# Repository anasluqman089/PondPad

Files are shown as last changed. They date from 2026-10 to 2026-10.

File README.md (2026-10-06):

# PondPad



Hello Everyone! PondPad is a custom arcade-style macropad built using a Seeed XIAO ESP32-C3. It uses 5 button, a TFT display and Bluetooth for quick shortcut, media, and text actions.

## Project contents

- Firmware: [Firmware/PondPadArcade.ino](Firmware/PondPadArcade.ino)
- Schematic and PCB: [PCB & Schematic/PondPad.kicad_sch](PCB%20%26%20Schematic/PondPad.kicad_sch) and [PCB & Schematic/PondPad.kicad_pcb](PCB%20%26%20Schematic/PondPad.kicad_pcb)
- Gerber output: [Production/Gerber](Production/Gerber)
- CAD files: [CAD](CAD)
- BOM: [BOM.csv](BOM.csv)

## Hardware

The current PCB is designed around:

- 1x Seeed XIAO ESP32-C3-SMD
- 5x Cherry MX-compatible 1.00u PCB switches
- 1x 240x320 ST7789-compatible TFT display
- 1x JST-PH 8-pin display interconnect
- 1x JST-PH 2-pin battery connector
- 4x M2 mounting holes

## BOM

| Name | Qty | Price | Buy Link |
| --- | ---: | --- | --- |
| Cherry MX switch | 5 | $8.75 | https://www.aliexpress.com/item/1005002162885278.html |
| XIAO ESP32-C3 | 1 | $12.00 | https://www.aliexpress.com/item/1005007469761633.html |
| JST PH 1x8 PCB mount | 1 | ~$0.20 | (Most only sells in pack more than 1) |
| JST PH 1x2 PCB mount | 1 | ~$0.20 | (Most only sells in pack more than 1) |
| M2 mounting screw | 4 | ~$0.50 | (Most only sells in pack more than 4) |
| 240x320 TFT display | 1 | $13.00 | https://www.aliexpress.com/item/1005008772378337.html] |
| PCB (With Stencil) | 1 | $7.80 | https://www.aliexpress.com/item/1005012672070003.html] |
| 3D Printing | 1 | ~$10.00 | - |

## Firmware

The firmware is written in Arduino C++.

### Required libraries

Install the following in the Arduino IDE or PlatformIO:

- Adafruit_GFX
- Adafruit_ST7789
- BleKeyboard
- Preferences support is built into the ESP32 core

### Pin map

The firmware expects the following GPIO assignments:

- Display backlight: GPIO 2
- Display reset: GPIO 3
- Display data/command: GPIO 4
- Display chip select: GPIO 5
- Key switches: GPIO 6, 7, 21, 9, 20
- SPI clock: GPIO 8
- SPI MOSI: GPIO 10

## Operation

The device starts in a menu screen and offers:

1. Macro pad mode
2. Fly Catch game
3. Whack-a-Frog game
4. Lily Dodge game
5. High score screen

The macro pad mode sends keyboard shortcuts and media commands over BLE to a paired host.

### Images



### PCB





### CAD





### Schematic

## License

This project is distributed under the repository license. See the [LICENSE](LICENSE) for details.

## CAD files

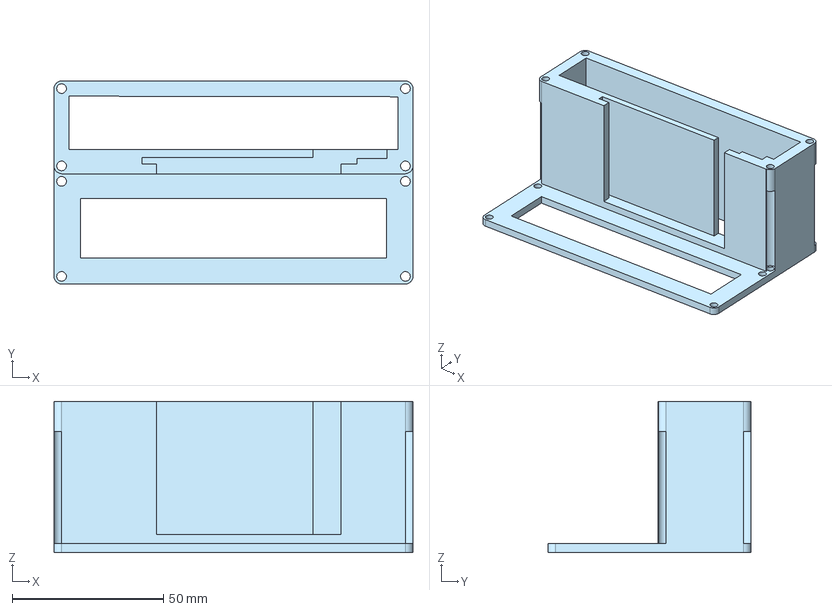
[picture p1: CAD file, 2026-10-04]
CAD/Screen Case & Keyboard Lid.step
118.5 x 67.0 x 50.0 mm

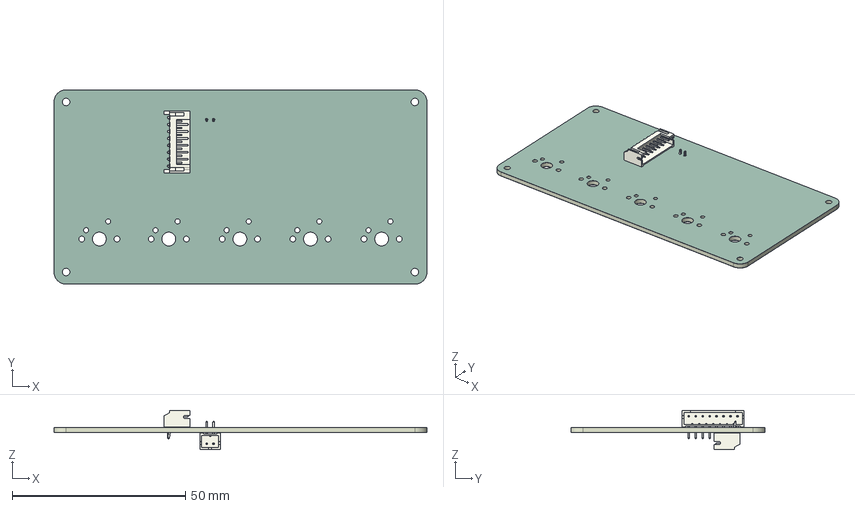
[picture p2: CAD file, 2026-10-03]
PCB & Schematic/PondPad PCB.step
107.5 x 56.0 x 11.4 mm
JST_S8B_PH_K
JST_S2B_PH_K
PonBE4F_soldermask x 2
PonBE4F_PCB

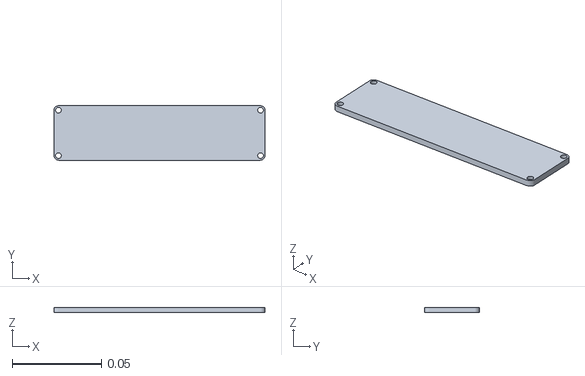
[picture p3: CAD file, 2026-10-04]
Production/3D Printing/Part 3.stl
0.118 x 0.0306 x 0.003

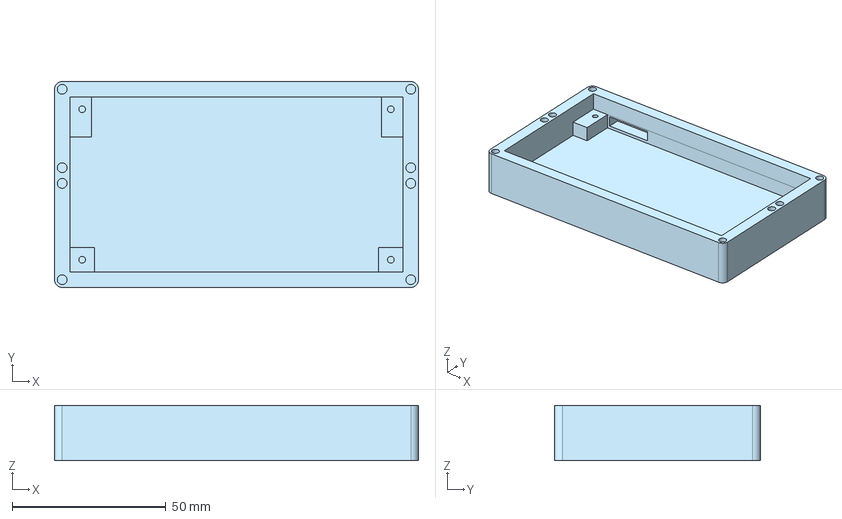
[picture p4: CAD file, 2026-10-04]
CAD/PCB Case.step
118.5 x 67.0 x 18.0 mm

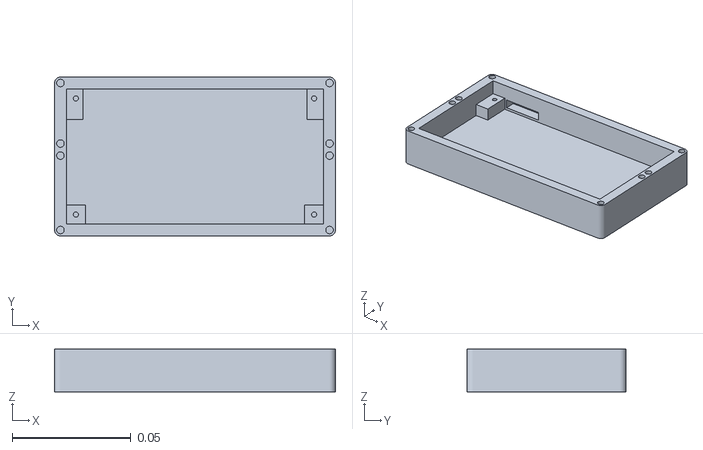
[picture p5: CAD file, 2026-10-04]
Production/3D Printing/Part 1.stl
0.118 x 0.067 x 0.018

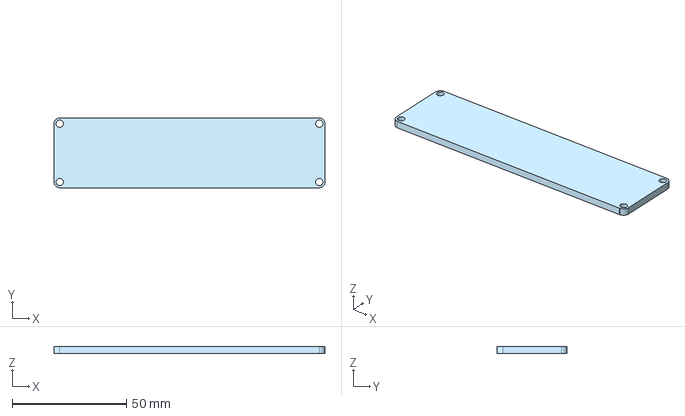
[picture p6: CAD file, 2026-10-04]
CAD/Screen Lid.step
118.5 x 30.6 x 3.00 mm

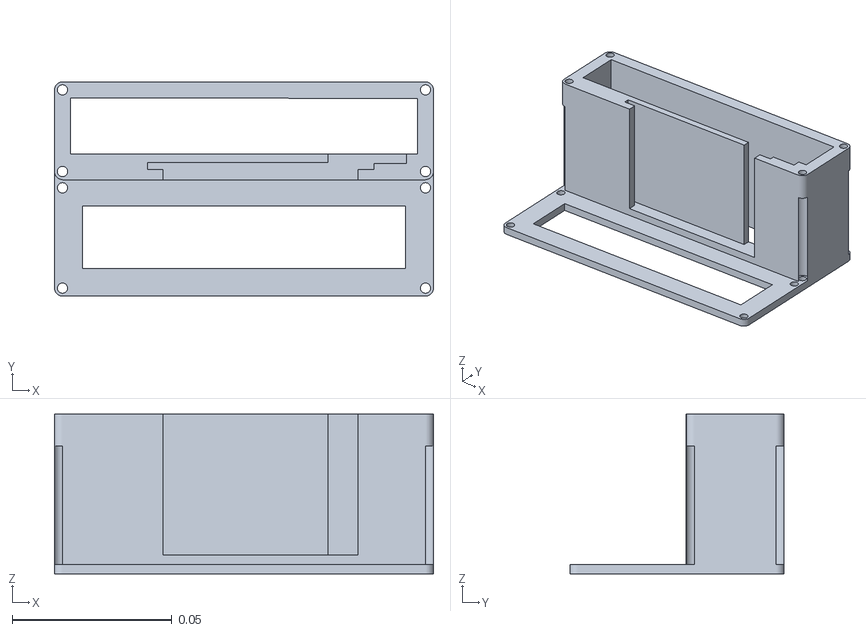
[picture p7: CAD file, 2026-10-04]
Production/3D Printing/Part 2.stl
0.118 x 0.067 x 0.05

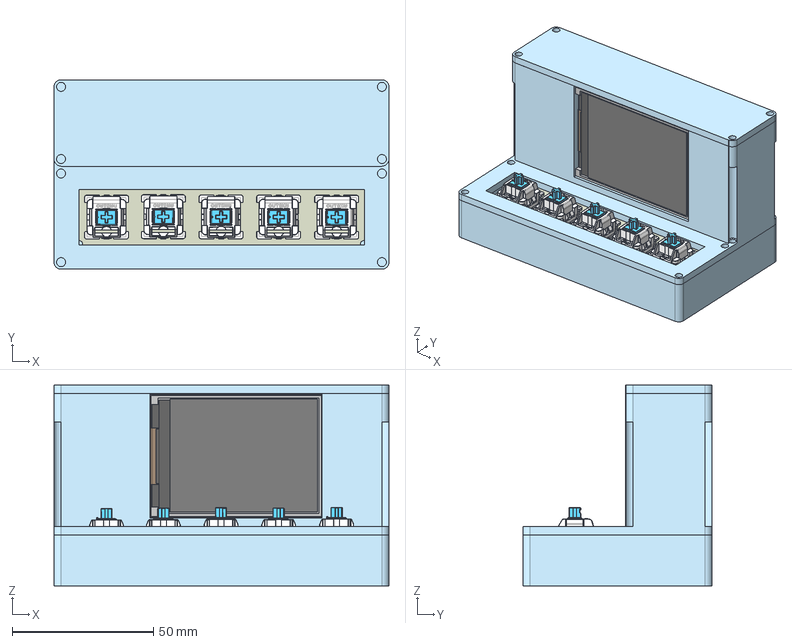
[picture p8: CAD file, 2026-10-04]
CAD/PondPad CAD.step
118.5 x 67.0 x 71.0 mm
Body - Flex
Extrude - Annular rings x 12
Support pins
Extrude - Connector pads x 8
BOSS-EXTRUDE7_9_:1__Körper1
BOSS-EXTRUDE7_7_:1__Körper1
RET__RET x 5
Body - LCD
Pins005
Body - Black tape
PIN__PIN x 10
BOSS-EXTRUDE14_9_:1__Körper1
BOSS-EXTRUDE7_6_:1__Körper1
BOSS-EXTRUDE7_4_:1__Körper1
BOSS-EXTRUDE14_3_:1__Körper1
Pins004
BOSS-EXTRUDE7_8_:1__Körper1
BOSS-EXTRUDE7_5_:1__Körper1
Shield:1__Körper1
U.FL Connector v1:1__Körper1
Cut - PCB
BOSS-EXTRUDE7_3_:1__Körper1
CLICK__CLICK x 5
TOP__TOP x 5
BOTT__BOTT x 5
Button (1):1__Körper1_1
BOSS-EXTRUDE14_10_:1__Körper1
Body - Adhesive
BOSS-EXTRUDE14_5_:1__Körper1
PonBE4F_PCB
Button (1):1__Körper1
BOSS-EXTRUDE14_11_:1__Körper1
Pins007
Main body
BOSS-EXTRUDE14_4_:1__Körper1
Pins006
Support pins001
JST_S8B_PH_K
Pins001
BOSS-EXTRUDE14_2_:1__Körper1
BOSS-EXTRUDE14_6_:1__Körper1
CUT-EXTRUDE5:1__Körper1
BOSS-EXTRUDE7_1_:1__Körper1
BOSS-EXTRUDE14_1_:1__Körper1
U.FL Connector v1:1__Körper3
Pins003
BOSS-EXTRUDE7_2_:1__Körper1
BOSS-EXTRUDE14_12_:1__Körper1
U.FL Connector v1:1__Körper2
BOSS-EXTRUDE14_7_:1__Körper1
Body - Protection
Pins002
BOSS-EXTRUDE14_8_:1__Körper1
MIRROR2:1__Körper1
Pins
Body - Bezel
JST_S2B_PH_K
PCB
CHAMFER9:1__Körper1

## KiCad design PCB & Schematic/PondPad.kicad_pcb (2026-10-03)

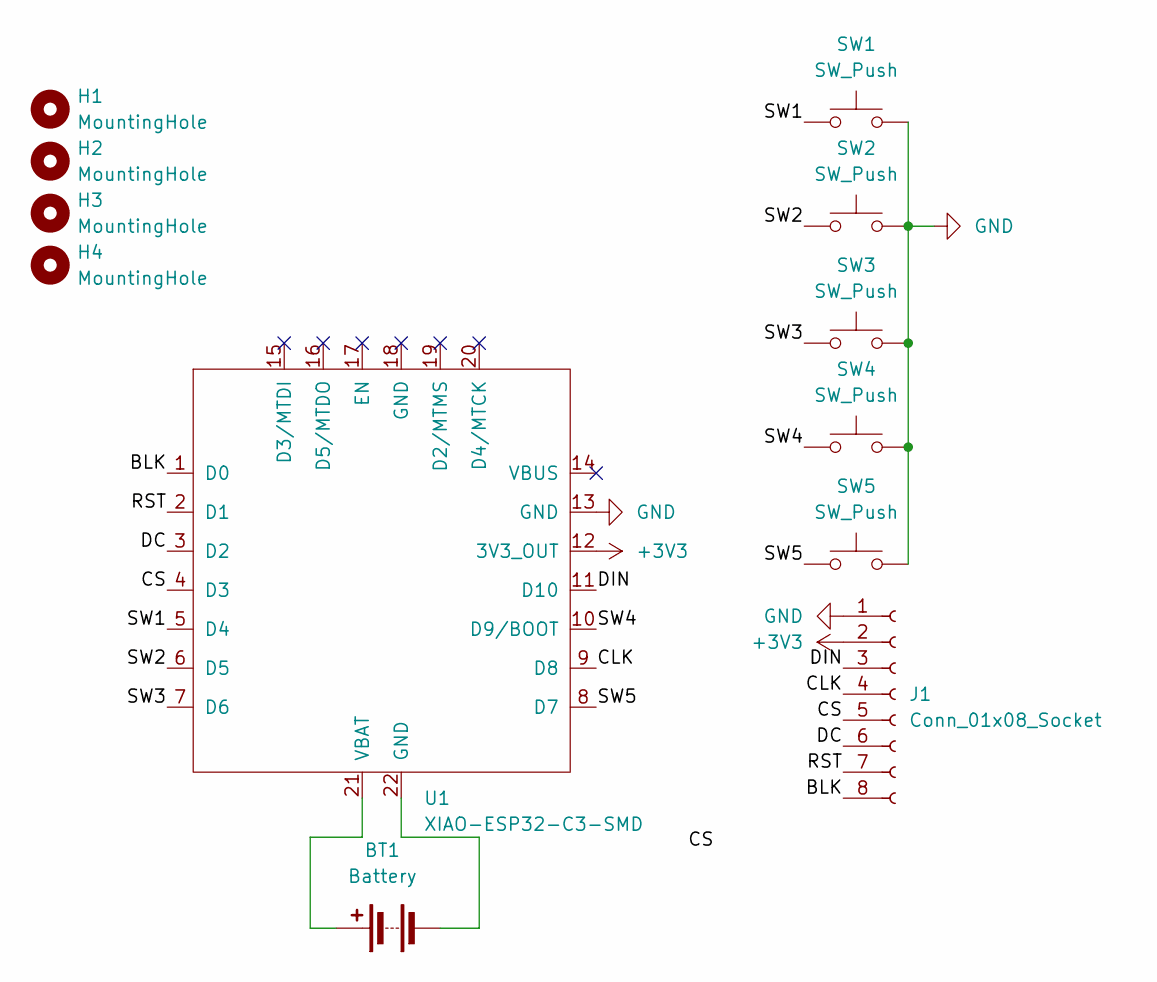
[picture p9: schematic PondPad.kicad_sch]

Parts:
BT1: Battery; JST_PH_S2B-PH-K_1x02_P2.00mm_Horizontal
H1, H2, H3, H4: MountingHole; MountingHole_2.2mm_M2
J1: Conn_01x08_Socket; JST_PH_S8B-PH-K_1x08_P2.00mm_Horizontal
SW1, SW2, SW3, SW4, SW5: SW_Push; SW_Cherry_MX_1.00u_PCB
U1: XIAO-ESP32-C3-SMD

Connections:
+3V3: J1.2, U1.12 (3V3_OUT)
/BLK: J1.8, U1.1 (D0)
/CLK: J1.4, U1.9 (D8)
/CS: J1.5, U1.4 (D3)
/DC: J1.6, U1.3 (D2)
/DIN: J1.3, U1.11 (D10)
/RST: J1.7, U1.2 (D1)
/SW1: SW1.1, U1.5 (D4)
/SW2: SW2.1, U1.6 (D5)
/SW3: SW3.1, U1.7 (D6)
/SW4: SW4.1, U1.10 (D9/BOOT)
/SW5: SW5.1, U1.8 (D7)
GND: J1.1, SW1.2, SW2.2, SW3.2, SW4.2, SW5.2, U1.13 (GND)
unnamed: BT1.1 (+), U1.21 (VBAT)
unnamed: BT1.2 (-), U1.22 (GND)

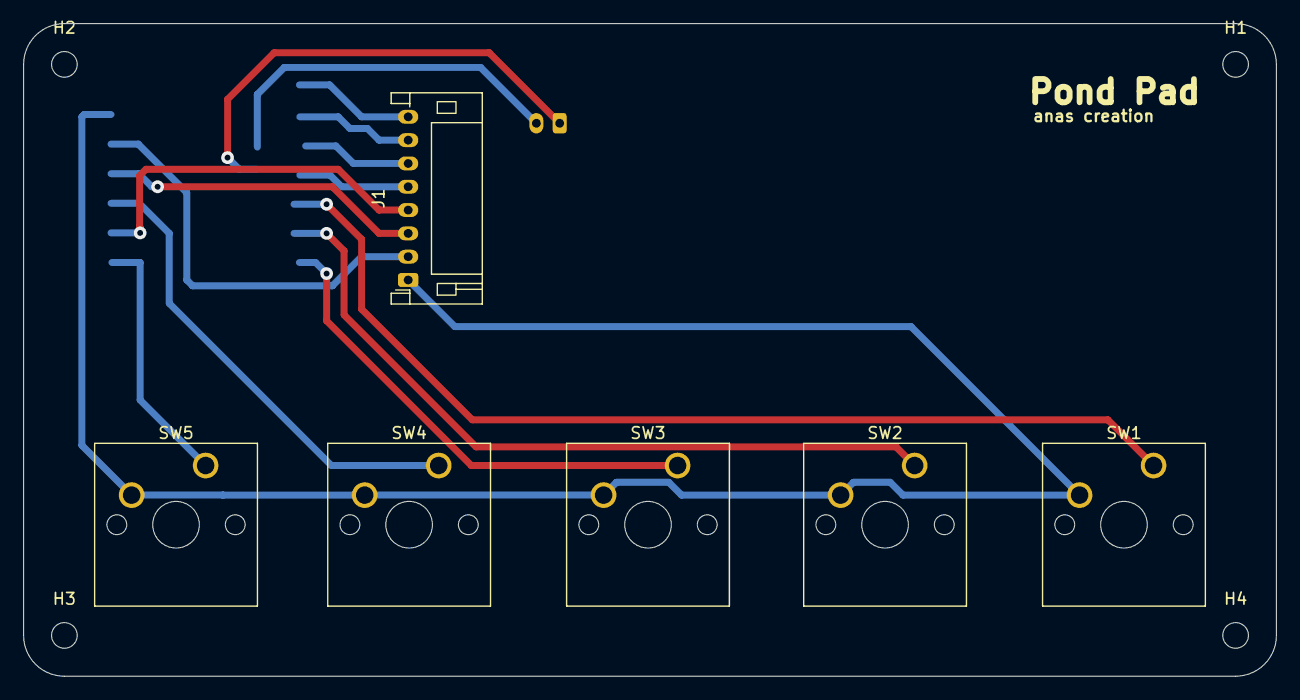
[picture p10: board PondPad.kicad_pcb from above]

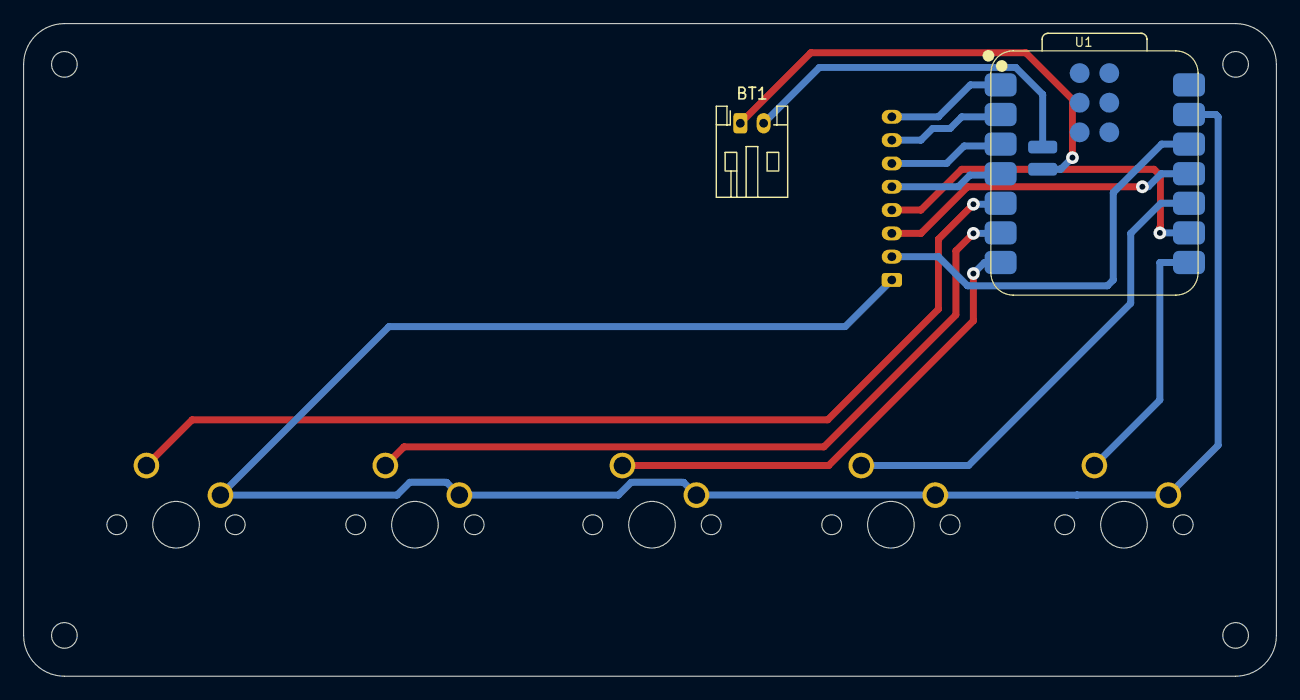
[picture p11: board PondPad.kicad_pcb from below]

Board: 2 copper layers, 107.5 x 56.0 mm, 12 parts (2 on the bottom side), 15 nets.

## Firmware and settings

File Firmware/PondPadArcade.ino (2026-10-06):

#include <SPI.h>
#include <math.h>
#include <Preferences.h>
#include <Adafruit_GFX.h>
#include <Adafruit_ST7789.h>
#include <BleKeyboard.h>

//Settings
#define MAC_MODE         false  
#define SCREEN_ROTATION  1       
#define LONG_PRESS_MS    600
#define CHORD_MS         800     
#define DEBOUNCE_MS      20
#define FRAME_MS         33      
#define DIM_AFTER_MS     30000
#define SLEEP_AFTER_MS   120000
#define BRIGHT_FULL      255
#define BRIGHT_DIM       40
#define BRIGHT_SLEEP     6

//Pins
#define PIN_BLK   2   
#define PIN_RST   3  
#define PIN_DC    4 
#define PIN_CS    5  
#define PIN_SW1   6  
#define PIN_SW2   7 
#define PIN_SW3   21  
#define PIN_SW5   20  
#define PIN_SCK   8   
#define PIN_SW4   9  
#define PIN_MOSI  10   

const uint8_t KEY_PINS[5] = {PIN_SW1, PIN_SW2, PIN_SW3, PIN_SW4, PIN_SW5};


//Colours
#define C_POND    0x0A29
#define C_HEADER  0x0145
#define C_LANE    0x1B6B
#define C_TEXT    0xE7F5
#define C_DIM     0xAD75
#define C_LILY    0x7F6B
#define C_GOLD    0xFE60
#define C_RED     0xF800
#define C_PINK    0xFBB5
#define TRANSP    0x0001   

const uint16_t ARC[5] = {0xF800, 0xFFE0, 0x07E0, 0x039F, 0xF81F}; 


//  Objects
Adafruit_ST7789 tft(&SPI, PIN_CS, PIN_DC, PIN_RST);
BleKeyboard bleKeyboard("Pond Pad", "Pond Labs", 100);
Preferences prefs;


//  Macro def
enum ActionType { ACT_COMBO, ACT_MEDIA, ACT_TEXT };

struct KeyDef {
  const char*    label;  
  const char*    sub;     
  ActionType     type;
  uint8_t        k1, k2, k3;
  const uint8_t* media;
  const char*    text;
};

#define COMBO(l, s, a, b, c) { l, s, ACT_COMBO, a, b, c, nullptr, nullptr }
#define MEDIA(l, s, m)       { l, s, ACT_MEDIA, 0, 0, 0, m, nullptr }
#define TEXT(l, s, t)        { l, s, ACT_TEXT,  0, 0, 0, nullptr, t }

struct Layer {
  const char* name;
  uint16_t    accent;
  KeyDef      keys[5];
};

#if MAC_MODE
  #define MOD KEY_LEFT_GUI
  #define SHOT_KEY '4'
#else
  #define MOD KEY_LEFT_CTRL
  #define SHOT_KEY 's'
#endif

const Layer LAYERS[] = {
  { "LILY PAD", 0x7F6B, {
      COMBO("COPY",  "Ctrl+C",     MOD, 'c', 0),
      COMBO("PSTE",  "Ctrl+V",     MOD, 'v', 0),
      COMBO("UNDO",  "Ctrl+Z",     MOD, 'z', 0),
      COMBO("SAVE",  "Ctrl+S",     MOD, 's', 0),
      COMBO("SNIP",  "Screenshot", KEY_LEFT_GUI, KEY_LEFT_SHIFT, SHOT_KEY),
  }},
  { "TADPOLE", 0xFD4B, {
      MEDIA("PREV",  "Track",  KEY_MEDIA_PREVIOUS_TRACK),
      MEDIA("PLAY",  "Pause",  KEY_MEDIA_PLAY_PAUSE),
      MEDIA("NEXT",  "Track",  KEY_MEDIA_NEXT_TRACK),
      MEDIA("VOL-",  "Volume", KEY_MEDIA_VOLUME_DOWN),
      MEDIA("VOL+",  "Volume", KEY_MEDIA_VOLUME_UP),
  }},
  { "FROG DEV", 0x5E9F, {
      COMBO("CMD",   "Palette",  MOD, KEY_LEFT_SHIFT, 'p'),
      COMBO("TERM",  "Terminal", MOD, '`', 0),
      COMBO("RUN",   "F5",       KEY_F5, 0, 0),
      COMBO("NOTE",  "Comment",  MOD, '/', 0),
      COMBO("FIND",  "In files", MOD, KEY_LEFT_SHIFT, 'f'),
  }},
  { "SPLASH", 0xFEA0, {
      TEXT("THX",   "Thanks!",  "Thanks!"),
      TEXT("BEST",  "Regards",  "Best regards,\n"),
      TEXT("SMLE",  "Smiley",   ":)"),
      TEXT("LGTM",  "Ship it",  "LGTM, ship it!"),
      TEXT("MAIL",  "Email",    "your@mail.com"),
  }},
};
const uint8_t NUM_LAYERS = sizeof(LAYERS) / sizeof(LAYERS[0]);


//  Global state
enum Mode : uint8_t { M_MENU, M_MACRO, M_FLY, M_WHACK, M_DODGE, M_SCORES, M_OVER };
Mode mode = M_MENU;

// layout
#define HUD_H     28
#define CATCH_Y   180
#define HIT_WIN   24
#define REMOVE_Y  206
#define FROG_Y    182
#define HINT_Y    231
#define POND_TOP  30
#define RIPPLE_Y  100
#define RIPPLE_MAX 26

inline int laneX(int i) { return 32 + i * 64; }
inline int imin(int a, int b) { return a < b ? a : b; }
inline int imax(int a, int b) { return a > b ? a : b; }

// player profile (saved)
uint32_t totalXP = 0, totalPresses = 0;
uint16_t hiScore[3] = {0, 0, 0};
uint32_t levelUpUntil = 0;

// power
uint32_t lastActivity = 0;
uint8_t  curBrightness = BRIGHT_FULL;
bool     lastConnected = false;

// input
struct KeyState {
  bool     down = false;
  bool     rawLast = false;
  uint32_t rawChangedAt = 0;
  uint32_t downSince = 0;
  bool     longFired = false;
};
KeyState ks[5];
uint32_t chordStart = 0;
bool     chordFired = false;
bool     exitRequested = false;

// macro mode
uint8_t  curLayer = 0;
uint8_t  comboCount = 0;
uint32_t lastComboAt = 0;
uint32_t lastHeaderAt = 0;

// ripples
struct Ripple { bool alive = false; int16_t x; int16_t r; uint16_t color; };
Ripple ripples[6];
uint32_t lastRippleTick = 0;

// menu
struct Firefly { int16_t x, y; };
Firefly flies[7];
uint32_t lastFireflyAt = 0, lastBlinkAt = 0;
bool blinkOn = true;

// game common
struct Obj { bool alive = false; uint8_t lane; uint8_t kind; float y; };  // kind 0 fly,1 golden,2 puffer
#define OBJ_N 14
Obj objs[OBJ_N];
int      score = 0, lives = 3, combo = 0;
bool     hudDirty = true;
uint32_t lastFrame = 0, lastSpawn = 0;

// fly catch
uint32_t tFlashUntil[5];
uint16_t tFlashCol[5];
bool     tFlashState[5];

// whack
struct Hole { uint8_t state; uint8_t kind; uint32_t until; };  // state 0 empty,1 up,2 feedback
Hole     holes[5];
char     fbText[5][6];
uint16_t fbCol[5];
uint32_t roundEnd = 0, nextPop = 0;
int      lastSecs = -1;

// dodge
uint8_t  frogLane = 2;
bool     frogDirty = true;
uint32_t frogFlashUntil = 0;
bool     frogWasFlash = false;

// game over
uint8_t  lastGame = 0;
int      lastScore = 0;
bool     lastNewHi = false, lastLevelUp = false;
uint16_t lastXpGain = 0;
uint32_t overReadyAt = 0;


void loadProfile() {
  prefs.begin("pondpad", true);
  totalXP      = prefs.getUInt("xp", 0);
  totalPresses = prefs.getUInt("presses", 0);
  hiScore[0]   = prefs.getUShort("hs0", 0);
  hiScore[1]   = prefs.getUShort("hs1", 0);
  hiScore[2]   = prefs.getUShort("hs2", 0);
  prefs.end();
}

void saveProfile() {
  prefs.begin("pondpad", false);
  prefs.putUInt("xp", totalXP);
  prefs.putUInt("presses", totalPresses);
  prefs.putUShort("hs0", hiScore[0]);
  prefs.putUShort("hs1", hiScore[1]);
  prefs.putUShort("hs2", hiScore[2]);
  prefs.end();
}

uint16_t levelFor(uint32_t xp) { return 1 + (uint16_t)sqrtf(xp / 20.0f); }

bool addXP(uint32_t n) {
  uint16_t before = levelFor(totalXP);
  totalXP += n;
  if (levelFor(totalXP) > before) {
    levelUpUntil = millis() + 2500;
    return true;
  }
  return false;
}

void setBacklight(uint8_t v) {
  curBrightness = v;
#if ESP_ARDUINO_VERSION_MAJOR >= 3
  ledcWrite(PIN_BLK, v);
#else
  ledcWrite(0, v);
#endif
}

void backlightInit() {
#if ESP_ARDUINO_VERSION_MAJOR >= 3
  ledcAttach(PIN_BLK, 5000, 8);
#else
  ledcSetup(0, 5000, 8);
  ledcAttachPin(PIN_BLK, 0);
#endif
  setBacklight(BRIGHT_FULL);
}

void wake() {
  lastActivity = millis();
  if (curBrightness != BRIGHT_FULL) setBacklight(BRIGHT_FULL);
}

void idleCheck() {
  uint32_t idle = millis() - lastActivity;
  if (idle > SLEEP_AFTER_MS && curBrightness != BRIGHT_SLEEP) setBacklight(BRIGHT_SLEEP);
  else if (idle > DIM_AFTER_MS && idle <= SLEEP_AFTER_MS && curBrightness != BRIGHT_DIM) setBacklight(BRIGHT_DIM);
}


void drawCentered(const char* s, int cx, int y, uint8_t size, uint16_t color, uint16_t bg) {
  int16_t x1, y1; uint16_t w, h;
  tft.setTextSize(size);
  tft.getTextBounds(s, 0, 0, &x1, &y1, &w, &h);
  if (bg == TRANSP) tft.setTextColor(color);
  else              tft.setTextColor(color, bg);
  tft.setCursor(cx - (int)w / 2 - x1, y);
  tft.print(s);
}

uint16_t blend565(uint16_t a, uint16_t b, uint8_t t) {
  int ar = (a >> 11) & 31, ag = (a >> 5) & 63, ab = a & 31;
  int br = (b >> 11) & 31, bg = (b >> 5) & 63, bb = b & 31;
  int r = ar + ((br - ar) * t) / 255;
  int g = ag + ((bg - ag) * t) / 255;
  int bl = ab + ((bb - ab) * t) / 255;
  return (r << 11) | (g << 5) | bl;
}

void drawHeart(int x, int y, uint16_t c) {
  tft.fillCircle(x - 3, y, 3, c);
  tft.fillCircle(x + 3, y, 3, c);
  tft.fillTriangle(x - 6, y + 1, x + 6, y + 1, x, y + 8, c);
}

void drawStar(int x, int y, int r, uint16_t c) {
  tft.fillTriangle(x, y - r, x - r * 87 / 100, y + r / 2, x + r * 87 / 100, y + r / 2, c);
  tft.fillTriangle(x, y + r, x - r * 87 / 100, y - r / 2, x + r * 87 / 100, y - r / 2, c);
}

void drawFly(int x, int y, uint8_t kind, uint8_t s) {
  uint16_t body = (kind == 1) ? C_GOLD : 0xB5B6;
  uint16_t wing = (kind == 1) ? 0xFFF0 : 0x7DFF;
  tft.fillCircle(x - 6 * s, y - 5 * s, 4 * s, wing);
  tft.fillCircle(x + 6 * s, y - 5 * s, 4 * s, wing);
  tft.fillCircle(x, y, 5 * s, body);
  tft.fillCircle(x - 2 * s, y - 2 * s, s, C_RED);
  tft.fillCircle(x + 2 * s, y - 2 * s, s, C_RED);
}

void drawPuffer(int x, int y) {
  static const int8_t SPX[8] = {14, 10, 0, -10, -14, -10, 0, 10};
  static const int8_t SPY[8] = {0, 10, 14, 10, 0, -10, -14, -10};
  for (int k = 0; k < 8; k++) tft.drawLine(x, y, x + SPX[k], y + SPY[k], C_GOLD);
  tft.fillCircle(x, y, 9, 0xFD20);
  tft.fillCircle(x, y + 3, 5, 0xFFE0);
  tft.fillCircle(x - 3, y - 3, 2, 0xFFFF);
  tft.fillCircle(x + 3, y - 3, 2, 0xFFFF);
  tft.drawPixel(x - 3, y - 3, 0x0000);
  tft.drawPixel(x + 3, y - 3, 0x0000);
}

void drawFrogFace(int x, int y, int r, uint16_t col) {
  int er = r * 4 / 10;
  int ex = r * 55 / 100, ey = r * 70 / 100;
  tft.fillCircle(x - ex, y - ey, er, col);
  tft.fillCircle(x + ex, y - ey, er, col);
  tft.fillCircle(x, y, r, col);
  tft.fillCircle(x - ex, y - ey, er * 6 / 10 + 1, 0xFFFF);
  tft.fillCircle(x + ex, y - ey, er * 6 / 10 + 1, 0xFFFF);
  tft.fillCircle(x - ex, y - ey, er / 4 + 1, 0x0000);
  tft.fillCircle(x + ex, y - ey, er / 4 + 1, 0x0000);
  tft.drawFastHLine(x - r / 2, y + r / 3, r, 0x0000);
  tft.drawFastHLine(x - r / 2, y + r / 3 + 1, r, 0x0000);
}

void drawSnake(int x, int y) {
  tft.fillRoundRect(x - 15, y - 14, 30, 28, 11, 0xA280);
  tft.fillCircle(x - 7, y - 4, 4, 0xFFE0);
  tft.fillCircle(x + 7, y - 4, 4, 0xFFE0);
  tft.drawFastVLine(x - 7, y - 7, 7, 0x0000);
  tft.drawFastVLine(x + 7, y - 7, 7, 0x0000);
  tft.drawLine(x, y + 6, x, y + 14, C_RED);
  tft.drawLine(x, y + 14, x - 3, y + 18, C_RED);
  tft.drawLine(x, y + 14, x + 3, y + 18, C_RED);
}


//Header
void drawHeader() {
  uint32_t now = millis();
  tft.fillRect(0, 0, 320, HUD_H, C_HEADER);

  uint16_t lv = levelFor(totalXP);
  char b[16];
  snprintf(b, sizeof(b), "LV%02u", lv);
  tft.setTextSize(2);
  tft.setTextColor(C_GOLD, C_HEADER);
  tft.setCursor(6, 6);
  tft.print(b);

  uint32_t lo = 20UL * (lv - 1) * (lv - 1);
  uint32_t hi = 20UL * lv * lv;
  int fill = (int)(70UL * (totalXP - lo) / (hi - lo));
  tft.drawRect(58, 9, 72, 10, C_LILY);
  tft.fillRect(59, 10, fill, 8, C_LILY);

  if (levelUpUntil && now < levelUpUntil) {
    if ((now / 250) & 1) drawCentered("LEVEL UP!", 177, 10, 1, C_GOLD, C_HEADER);
  } else if (mode == M_MACRO && comboCount >= 2) {
    snprintf(b, sizeof(b), "COMBO x%u", comboCount);
    drawCentered(b, 177, 10, 1, ARC[comboCount % 5], C_HEADER);
  } else {
    drawCentered("PLAYER 1", 177, 10, 1, C_DIM, C_HEADER);
  }

  bool c = bleKeyboard.isConnected();
  uint16_t col = c ? 0x07E0 : 0xFD20;
  tft.fillCircle(232, 13, 5, col);
  tft.setTextSize(1);
  tft.setTextColor(col, C_HEADER);
  tft.setCursor(244, 10);
  tft.print(c ? "LINKED" : "PAIRING");
  tft.drawFastHLine(0, HUD_H - 1, 320, C_LILY);
  lastHeaderAt = now;
}

void headerTick(uint32_t now) {
  if (levelUpUntil) {
    if (now >= levelUpUntil) { drawHeader(); levelUpUntil = 0; }
    else if (now - lastHeaderAt > 250) drawHeader();
  }
}

void suppressHeld() {
  uint32_t now = millis();
  for (uint8_t i = 0; i < 5; i++) {
    bool raw = (digitalRead(KEY_PINS[i]) == LOW);
    ks[i].down = raw;
    ks[i].rawLast = raw;
    ks[i].rawChangedAt = now;
    ks[i].downSince = now;
    ks[i].longFired = true;
  }
}


//  Ripples
void ringDraw(int cx, int r, uint16_t color) {
  if (r > 0) tft.drawCircle(cx, RIPPLE_Y, r, color);
  if (r > 6) tft.drawCircle(cx, RIPPLE_Y, r - 6, color);
}

void spawnRipple(uint8_t keyIndex, uint16_t color) {
  for (auto& r : ripples) {
    if (!r.alive) {
      r.alive = true; r.x = laneX(keyIndex); r.r = 2; r.color = color;
      return;
    }
  }
}

void updateRipples() {
  if (millis() - lastRippleTick < 35) return;
  lastRippleTick = millis();
  for (auto& r : ripples) {
    if (!r.alive) continue;
    ringDraw(r.x, r.r, C_POND);
    r.r += 2;
    if (r.r > RIPPLE_MAX) { r.alive = false; continue; }
    uint8_t fade = (uint16_t)r.r * 255 / RIPPLE_MAX;
    ringDraw(r.x, r.r, blend565(r.color, C_POND, fade));
  }
}


//menu
const char* MENU_A[5] = {"MACRO",  "FLY",   "WHACK",  "LILY",  "HI"};
const char* MENU_B[5] = {"PAD",    "CATCH", "A FROG", "DODGE", "SCORES"};

void drawMenuTile(uint8_t i) {
  int cx = laneX(i), cy = 165;
  tft.fillRect(i * 64 + 1, 134, 62, 104, C_HEADER);
  tft.fillRoundRect(cx - 27, 138, 54, 54, 8, 0x0841);
  tft.drawRoundRect(cx - 27, 138, 54, 54, 8, ARC[i]);
  switch (i) {
    case 0:
      for (int r = 0; r < 2; r++)
        for (int k = 0; k < 5; k++)
          tft.fillRect(cx - 24 + k * 10, 151 + r * 12, 8, 8, ARC[k]);
      tft.fillRect(cx - 16, 176, 32, 6, C_TEXT);
      break;
    case 1: drawFly(cx, cy + 2, 0, 2); break;
    case 2: drawFrogFace(cx, cy + 4, 14, 0x47E0); break;
    case 3: drawPuffer(cx, cy); break;
    case 4: drawStar(cx, cy, 18, C_GOLD); break;
  }
  drawCentered(MENU_A[i], cx, 198, 1, C_TEXT, C_HEADER);
  drawCentered(MENU_B[i], cx, 210, 1, ARC[i], C_HEADER);
  char b[8]; snprintf(b, sizeof(b), "KEY %d", i + 1);
  drawCentered(b, cx, 225, 1, C_DIM, C_HEADER);
}

void enterMenu() {
  mode = M_MENU;
  suppressHeld();
  tft.fillScreen(C_POND);
  drawHeader();
  drawCentered("POND PAD", 164, 38, 4, C_HEADER, TRANSP);   // shadow
  drawCentered("POND PAD", 160, 34, 4, C_LILY, TRANSP);
  drawCentered("A R C A D E", 160, 74, 2, C_GOLD, TRANSP);
  tft.fillRect(0, 132, 320, 108, C_HEADER);
  tft.drawFastHLine(0, 132, 320, C_LILY);
  for (uint8_t i = 0; i < 5; i++) drawMenuTile(i);
  for (auto& f : flies) { f.x = random(10, 310); f.y = random(110, 128); }
  blinkOn = true;
  lastBlinkAt = millis();
  for (auto& r : ripples) r.alive = false;
}

void menuTick(uint32_t now) {
  headerTick(now);

  if (now - lastBlinkAt > 500) {
    lastBlinkAt = now;
    blinkOn = !blinkOn;
    drawCentered("- PICK YOUR GAME -", 160, 96, 1, blinkOn ? C_TEXT : C_POND, C_POND);
  }

  if (now - lastFireflyAt > 140) {
    lastFireflyAt = now;
    for (auto& f : flies) {
      tft.fillRect(f.x - 1, f.y - 1, 3, 3, C_POND);
      f.x += random(-5, 6);
      f.y += random(-2, 3);
      if (f.x < 4) f.x = 4;
      if (f.x > 315) f.x = 315;
      if (f.y < 108) f.y = 108;
      if (f.y > 127) f.y = 127;
      uint16_t c = random(3) ? C_GOLD : 0xFFF0;
      tft.fillRect(f.x - 1, f.y - 1, 3, 3, c);
    }
  }
}


//Mode
void drawMacroPond() {
  const Layer& L = LAYERS[curLayer];
  tft.fillRect(0, HUD_H, 320, 132 - HUD_H, C_POND);
  drawCentered(L.name, 160, 38, 3, L.accent, C_POND);
  int total = NUM_LAYERS * 14;
  int sx = 160 - total / 2 + 7;
  for (uint8_t i = 0; i < NUM_LAYERS; i++) {
    if (i == curLayer) tft.fillCircle(sx + i * 14, 72, 4, L.accent);
    else               tft.drawCircle(sx + i * 14, 72, 3, C_LANE);
  }
}

void drawArcadeButton(uint8_t i, bool pressed) {
  const Layer& L = LAYERS[curLayer];
  const KeyDef& k = L.keys[i];
  int cx = laneX(i), cy = 158;
  uint16_t col = ARC[i];

  tft.fillRect(i * 64 + 1, 134, 62, 104, C_HEADER);
  tft.fillCircle(cx, cy, 28, 0x2104);
  tft.drawCircle(cx, cy, 28, 0x528A);
  if (pressed) {
    tft.fillCircle(cx, cy + 2, 23, blend565(col, 0x0000, 120));
  } else {
    tft.fillCircle(cx, cy - 1, 24, col);
    tft.fillCircle(cx - 8, cy - 9, 6, blend565(col, 0xFFFF, 140));
  }
  uint8_t sz = (strlen(k.label) * 12 <= 58) ? 2 : 1;
  drawCentered(k.label, cx, 196, sz, pressed ? L.accent : C_TEXT, C_HEADER);
  drawCentered(k.sub, cx, 220, 1, C_DIM, C_HEADER);
}

void enterMacro() {
  mode = M_MACRO;
  comboCount = 0;
  suppressHeld();
  tft.fillScreen(C_POND);
  drawHeader();
  drawMacroPond();
  tft.fillRect(0, 132, 320, 108, C_HEADER);
  tft.drawFastHLine(0, 132, 320, C_LILY);
  for (uint8_t i = 0; i < 5; i++) drawArcadeButton(i, false);
  for (auto& r : ripples) r.alive = false;
}

void changeLayer(int dir) {
  curLayer = (curLayer + NUM_LAYERS + dir) % NUM_LAYERS;
  drawMacroPond();
  for (uint8_t i = 0; i < 5; i++) drawArcadeButton(i, ks[i].down);
}

void runAction(uint8_t i) {
  if (!bleKeyboard.isConnected()) return;
  const KeyDef& k = LAYERS[curLayer].keys[i];
  switch (k.type) {
    case ACT_COMBO:
      if (k.k1) bleKeyboard.press(k.k1);
      if (k.k2) bleKeyboard.press(k.k2);
      if (k.k3) bleKeyboard.press(k.k3);
      delay(25);
      bleKeyboard.releaseAll();
      break;
    case ACT_MEDIA: bleKeyboard.write(k.media); break;
    case ACT_TEXT:  bleKeyboard.print(k.text); break;
  }
}

void macroPress(uint8_t i) {
  drawArcadeButton(i, true);
  spawnRipple(i, LAYERS[curLayer].accent);
}

void macroRelease(uint8_t i) {
  drawArcadeButton(i, false);
  if (ks[i].longFired) return;

  bool sent = false;
  if (bleKeyboard.isConnected()) {
    runAction(i);
    sent = true;
  }

  if (!sent) return;

  uint32_t now = millis();
  comboCount = (now - lastComboAt < 2500 && comboCount < 250) ? comboCount + 1 : 1;
  lastComboAt = now;

  uint32_t xp = 1;
  if (comboCount % 5 == 0) {            // combo milestone!
    xp += 2;
    for (uint8_t k = 0; k < 5; k++) spawnRipple(k, ARC[k]);
  }
  addXP(xp);
  totalPresses++;
  if (totalPresses % 25 == 0) saveProfile();
  drawHeader();
}

void macroTick(uint32_t now) {
  updateRipples();
  if (comboCount && now - lastComboAt > 2500) { comboCount = 0; drawHeader(); }
  headerTick(now);
}


//game
void drawGameHud() {
  tft.fillRect(0, 0, 320, HUD_H, C_HEADER);
  char b[20];
  snprintf(b, sizeof(b), "SCORE %d", score);
  tft.setTextSize(2);
  tft.setTextColor(C_TEXT, C_HEADER);
  tft.setCursor(6, 6);
  tft.print(b);

  if (combo >= 2) {
    snprintf(b, sizeof(b), "x%d", combo);
    drawCentered(b, 205, 6, 2, C_GOLD, C_HEADER);
  }
  if (mode == M_WHACK) {
    int s = lastSecs < 0 ? 30 : lastSecs;
    snprintf(b, sizeof(b), "T%02d", s);
    tft.setTextColor(s <= 5 ? C_RED : C_TEXT, C_HEADER);
    tft.setCursor(262, 6);
    tft.print(b);
  } else {
    for (int h = 0; h < 3; h++) drawHeart(272 + h * 18, 12, h < lives ? C_RED : 0x2104);
  }
  tft.drawFastHLine(0, HUD_H - 1, 320, C_LILY);
}

void drawHints() {
  for (int i = 0; i < 5; i++) {
    tft.fillCircle(laneX(i), HINT_Y, 8, ARC[i]);
    char b[2] = {(char)('1' + i), 0};
    drawCentered(b, laneX(i), HINT_Y - 3, 1, 0x0000, TRANSP);
  }
}

void eraseObj(uint8_t k) {
  tft.fillRect(laneX(objs[k].lane) - 16, (int)objs[k].y - 16, 32, 34, C_POND);
}

void drawObj(uint8_t k) {
  int cx = laneX(objs[k].lane), y = (int)objs[k].y;
  if (objs[k].kind == 2) drawPuffer(cx, y);
  else                   drawFly(cx, y, objs[k].kind, 1);
}

void spawnObj() {
  for (int t = 0; t < 6; t++) {
    uint8_t lane = random(5);
    bool busy = false;
    for (auto& o : objs) if (o.alive && o.lane == lane && o.y < 90) busy = true;
    if (busy) continue;
    for (auto& o : objs) {
      if (!o.alive) {
        o.alive = true; o.lane = lane; o.y = HUD_H + 20;
        if (mode == M_FLY) o.kind = (random(100) < 8) ? 1 : 0;
        else {
          int pct = imin(55, 28 + score / 40);
          o.kind = (random(100) < pct) ? 2 : 0;
        }
        return;
      }
    }
    return;
  }
}

void countdown() {
  tft.fillScreen(C_POND);
  drawCentered("GET READY", 160, 60, 2, C_TEXT, C_POND);
  for (int n = 3; n >= 1; n--) {
    char b[2] = {(char)('0' + n), 0};
    tft.fillRect(100, 100, 120, 60, C_POND);
    drawCentered(b, 160, 102, 6, C_GOLD, C_POND);
    delay(420);
  }
  tft.fillRect(100, 100, 120, 60, C_POND);
  drawCentered("GO!", 160, 108, 5, 0x07E0, C_POND);
  delay(350);
}

void drawOver() {
  tft.fillRoundRect(40, 50, 240, 140, 10, C_HEADER);
  tft.drawRoundRect(40, 50, 240, 140, 10, C_GOLD);
  tft.drawRoundRect(42, 52, 236, 136, 8, C_GOLD);
  drawCentered("GAME OVER", 160, 62, 3, C_RED, C_HEADER);
  char b[28];
  snprintf(b, sizeof(b), "SCORE %d", lastScore);
  drawCentered(b, 160, 96, 2, C_TEXT, C_HEADER);
  if (lastNewHi) drawCentered("NEW HIGH SCORE!", 160, 120, 2, C_GOLD, C_HEADER);
  else {
    snprintf(b, sizeof(b), "BEST %u", hiScore[lastGame]);
    drawCentered(b, 160, 120, 2, C_DIM, C_HEADER);
  }
  snprintf(b, sizeof(b), "+%u XP%s", lastXpGain, lastLevelUp ? "  LEVEL UP!" : "");
  drawCentered(b, 160, 148, 1, lastLevelUp ? C_GOLD : C_LILY, C_HEADER);
}

void endGame(uint8_t g) {
  lastGame = g;
  lastScore = score;
  lastNewHi = score > hiScore[g];
  if (lastNewHi) hiScore[g] = score;
  lastXpGain = score / 10 + (lastNewHi ? 5 : 0);
  lastLevelUp = addXP(lastXpGain);
  saveProfile();
  mode = M_OVER;
  overReadyAt = millis() + 900;
  blinkOn = false;
  lastBlinkAt = 0;
  drawOver();
}

void overTick(uint32_t now) {
  if (now < overReadyAt) return;
  if (now - lastBlinkAt > 450) {
    lastBlinkAt = now;
    blinkOn = !blinkOn;
    drawCentered("PRESS ANY KEY", 160, 166, 1, blinkOn ? C_TEXT : C_HEADER, C_HEADER);
  }
}
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
void loop() {
  scanButtons();
  uint32_t now = millis();

  if (exitRequested) {
    exitRequested = false;
    if (mode != M_MENU) {
      if (mode == M_MACRO) saveProfile();
      enterMenu();
    }
  }

  switch (mode) {
    case M_MENU:   menuTick(now); break;
    case M_MACRO:  macroTick(now); break;
    case M_FLY:
    case M_WHACK:
    case M_DODGE:
      if (now - lastFrame >= FRAME_MS) {
        lastFrame = now;
        if (mode == M_FLY) flyTick(now);
        else if (mode == M_WHACK) whackTick(now);
        else dodgeTick(now);
      }
      break;
    case M_SCORES: scoresTick(now); break;
    case M_OVER:   overTick(now); break;
  }

  idleCheck();

  bool c = bleKeyboard.isConnected();
  if (c != lastConnected) {
    lastConnected = c;
    if (mode == M_MENU || mode == M_MACRO) drawHeader();
    wake();
  }

  delay(1);
}

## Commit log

2026-10-03 Add gerber, firmware and PCB file
    [PondPad PCB.step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]
2026-10-04 Add CAD file and .stl file for 3D printing
    [PCB Case.step, Part 1.stl, Part 2.stl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]
2026-10-06 Updated the code, REadme and BOM
    [BOM.csv]
2026-10-06 Fix BOM links and add image sections
    Updated BOM links to remove markdown formatting and added image sections for PCB, CAD, and schematic.
